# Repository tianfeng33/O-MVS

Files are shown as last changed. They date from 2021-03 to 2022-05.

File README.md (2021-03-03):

# O-MVS
The PCB designs for the Open MVS
These were made and released public in the hopes of promoting the simple, correct and safe consolitation of MVS systems and projects. 
This is V1.3 of the boards designed for the O-MVS project.  

These were designed using EASYEDA and I don't have a schematic specific for this design.
The KiCAD files were generated using https://wokwi.com/easyeda2kicad and have not be checked or tested for accuracy. 
They are meant for people to develop or modify so they can create derivative projects.

If you wish to use the project as is, please have boards made using the Gerbers or the files on OSH PARK. 
These have been tested thoroughly and I hold no responsibility for any damage to your MVS units or your equipment. 

Have fun and make some cool shit for the community.

TF

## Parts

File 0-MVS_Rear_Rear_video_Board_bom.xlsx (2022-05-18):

ID | Name | Designator | Footprint | Quantity
1 | 47uf/10v | C17,C16 | CP_TANTALUM_CASE-B | 2
2 | 100k | R10,R15 | 0603' 1% | 2
3 | 68pF/50V | C11,C14 | 0603' C0G | 2
4 | 1.33k | R8,R7,R9,R6 | 0603' 1% | 4
5 | 0.1uF/50V | C15,C2,C6,C5,C4,C3, | 0603' x7r | 6
6 | 22uF/10V | C1 | 1210 x7r | 1
7 | 330 | R17,R16 | 0603' 1% | 2
8 | 300k | R11,R14 | 0603' 1% | 2
9 | 10.0k | R13,R12 | 0603' 1% | 2
10 | 5.62k | R5,R4,R3,R2 | 0603' 1% | 4
11 | THS7374IPWR | U1 | TSSOP-14 | 1
12 | 10uf/10v | C10,C13 | 0805' x7r | 2
13 | OPA1678IDR | U2 | SOIC-8 | 1
14 | B6B-XH-A(LF)(SN),2.5mm. | j1 | jst-xh-6p | 1
15 | MD-90SM | CON1 | MD-90SM | 1
16 | B2B-XH-A(LF)(SN),2.5mm | Audio | jst xh 2p | 1
17 | 220uf/10v | C18 | Tantlum Case B | 1
18 | 10uf/10v | C12 | Tantalum Case A | 1
19 | 75ohm | r18 | 0603' 1% | 1

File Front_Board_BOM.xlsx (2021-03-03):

ID | Name | Designator | Footprint | Quantity
1 | 0.1uF/50V | c3 | 0603' x7r | 1
2 | 22uF/10V | C1,C2 | 1210 x7r | 2
3 | 1k | r1 | 0603' 1% | 1
4 | STEF04spur | U1 | DFN 3x3 10L | 1
5 | PB400EEQR1BLK | SW1 |  | 1
6 | PB400OAQR1BLK | SW2 |  | 1
7 | A-DS 15 A/KG-T4S | P1,P2 | Dsub 15 2 row | 2
8 | B6B-XH-A(LF)(SN),2.5mm. | AV-Out | B6B-XH-A(LF)(SN),2.5mm. | 1
9 | B2B-XH-A(LF)(SN),2.5mm | LED | B2B-XH-A(LF)(SN),2.5mm | 1
10 | EBM28DRXH | Jamma | 28x2 3.96 card edge female | 1

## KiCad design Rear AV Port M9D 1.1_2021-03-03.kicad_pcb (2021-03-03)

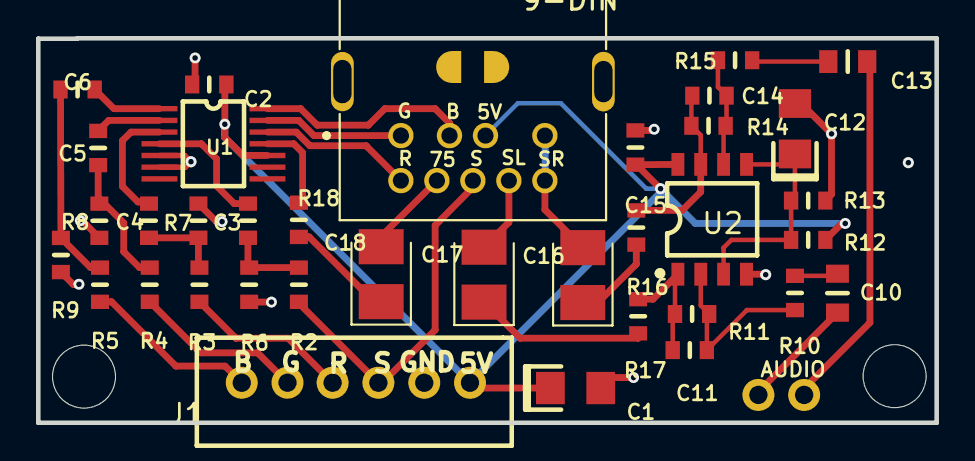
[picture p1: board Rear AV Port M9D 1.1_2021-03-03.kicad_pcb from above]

Board: 2 copper layers, 49.9 x 21.4 mm, 39 parts (0 on the bottom side), 15 nets.

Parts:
9-DIN: MD-90SM; CUI_MD-90SM
AUDIO: JST 2.5
C1, C12: 22uF/10V; 1206_P
C2, C15: 0.1uF/50V; 0603
C3, C4, C5, C6, C11, C14: 270pF/50V; 0603
C10, C13: 0805
C16, C17, C18: CP_TANTALUM_CASE-B_EIA-3528-21_REFLOW
J1: 6PIN_2.54_MM_JST_XHP_JST_CONNECTOR BRO COPY
R2, R3, R4, R5: 5.62k; 0603
R6, R7, R8, R9, R18: 1.00k; 0603
R10, R15: 6.19k; 0603
R11, R14: 162k; 0603
R12, R13: 10.0k; 0603
R16, R17: 332; 0603
U1: THS7374IPWR; TSSOP-14
U2: DMP-8
U5, U6: M3

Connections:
+5V: 9-DIN.2, C1.1, C2.1, C15.1, J1.1, R12.1, U1.10, U2.8
B-OUT: 9-DIN.1, U1.14
BLUE: C6.1, C6.2, J1.6, R5.1, R5.2, R9.2, U1.1
G-OUT: 9-DIN.3, U1.13
GND: 9-DIN.S1, 9-DIN.S2, 9-DIN.S3, C1.2, C2.2, C12.2, C15.2, J1.2, R6.1, R7.1, R8.1, R9.1, R13.1, U1.5, U1.6, U1.9, U2.4
GREEN: C5.1, C5.2, J1.5, R4.1, R4.2, R8.2, U1.2
LEFT: 9-DIN.8, AUDIO.3, C10.1, C10.2, C11.1, C11.2, C17.2, R10.1, R10.2, R11.1, R11.2, R17.2, U2.1, U2.2
R-OUT: 9-DIN.7, U1.12
RED: C4.1, C4.2, J1.4, R3.1, R3.2, R7.2, U1.3
RIGHT: 9-DIN.6, 9-DIN.9, AUDIO.4, C13.1, C13.2, C14.1, C14.2, C16.2, R14.1, R14.2, R15.1, R15.2, R16.1, U2.6, U2.7
SL: C17.1, R17.1
SR: C16.1, R16.2
SYNC: 9-DIN.5, C3.1, C3.2, J1.3, R2.1, R2.2, R6.2, U1.4
SYNC-75: 9-DIN.4, C18.1, C18.2, R18.1, R18.2, U1.11
VREF: C12.1, R12.2, R13.2, U2.3, U2.5

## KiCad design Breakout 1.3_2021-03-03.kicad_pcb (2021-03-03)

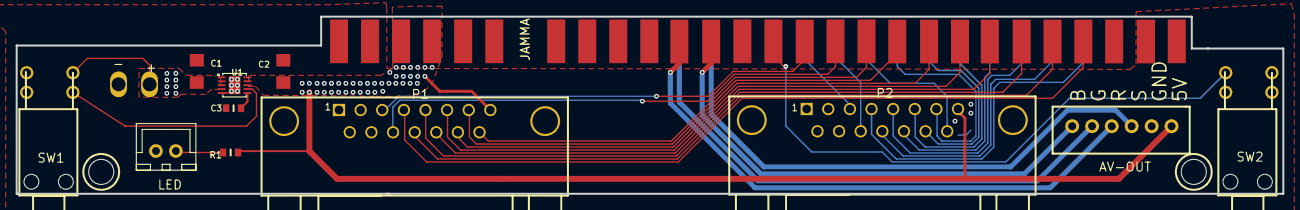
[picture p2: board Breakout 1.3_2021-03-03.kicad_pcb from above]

Board: 2 copper layers, 161.7 x 22.6 mm, 15 parts (0 on the bottom side), 30 nets.

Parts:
+: 3.96MM 2P
C1, C2: R1206
C3: 0.1uF/50V; 0603
J1: 6PIN_2.54_MM_JST_XHP_JST_CONNECTOR BRO COPY
LED: JST_XH_2X2.54
P1, P2: Controller 1; DB15-M-DC
R1: 270pF/50V; 0603
SW1, SW2: PB400EEQR1BLK(CORRECT)
U1: EFUSE
U2, U5: M3 HOLE
U4: JAMMA SOLDER SIDE

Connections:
1PA: P1.13, U4.22
1PB: P1.5, U4.23
1PC: P1.12, U4.24
1PCOIN: P1.3, U4.16
1PD: P1.4, U4.25
1PDN: P1.7, U4.19
1PL: P1.14, U4.20
1PR: P1.6, U4.21
1PST: P1.11, U4.17
1PUP: P1.15, U4.18
2PA: P2.13, U4.Z
2PB: P2.5, U4._A
2PC: P2.12, U4._B
2PCOIN: P2.3, U4.T
2PD: P2.4, U4._C
2PDN: P2.7, U4.W
2PL: P2.14, U4.X
2PR: P2.6, U4.Y
2PST: P2.11, U4.U
2PUP: P2.15, U4.V
+5V: C2.1, J1.1, LED.1, P1.8, P2.8, R1.1, R1.2, U1.8, U1.9, U1.10, U4.3, U4.4, U4.C, U4.D
B: J1.6, U4.13
EN: SW1.4, U1.7
G: J1.5, U4.N
GND: +.1, C1.2, C2.2, C3.2, J1.2, LED.2, P1.0, P1.1, P2.0, P2.1, SW2.2, SW2.4, U1.5, U1.11, U4.1, U4.2, U4.27, U4.28, U4.A, U4.B, U4._E, U4._F
R: J1.4, U4.12
S: J1.3, U4.P
SST: C3.1, U1.6
TEST: SW2.1, U4.15
V-IN: +.2, C1.1, SW1.3, U1.1, U1.2, U1.3, U1.4

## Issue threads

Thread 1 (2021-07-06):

Component BOM unavailable

edacraneo, 2021-07-06:
Hello,
Thanks for your great job, I'm trying to find the material available in the boom file but some products are unavailable. Would it be possible to have up-to-date BOM files? for example, the STEF04spur component cannot be found on the webt, is there an alternative?

Thank you so much

Regards

tianfeng33, 2021-07-07:
Hi,  it might just be the labeling.  https://www.digikey.ca/en/products/detail/stmicroelectronics/STEF4SPUR/4383954?s=N4IgTCBcDaIMoBcCmAzALCAugXyA

It is probably an stef4s now and not 04. That link should work and I will update the bom later today.

edacraneo, 2021-07-07:
Thank you Tianfeng33 for the link but 0 in stock and 28 Weeks for new stock..
Not possible to use another component ? identical please ?

Than you a lot

Regards

tianfeng33, 2021-07-07:
No, just use that since it is not EOL. Arrow has stock.  You just needed to google it. https://www.arrow.com/en/products/stef4spur/stmicroelectronics

edacraneo, 2021-07-07:
yes indeed I was looking for the components especially in France, Thank you again for your help.
Have a nice day

Closed 2021-07-07.

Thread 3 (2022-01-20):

Capacitors

monkzzz, 2022-01-20:
Regarding the tantalum capacitors C12, C16, C17, C18 in the OMVS AV board:
Are they all solid smd or are they polimer?
Is the C12 really a tantalum capacitor? Or a typical MLCC?
Does the C18 really need to be 10v? or can it be a 6,3v?

Glimmerman1984, 2022-03-06:
As above, has the C18 need to be 10V, or can it be 6,3V?
I cant find a Case B 22uF with 10V, only 6,3V or an Case C with 10V.

tianfeng33, 2022-03-07:
C18 should be fine at 6.3v.  C12 needs to be tantalum. The 22uf at c1 can be a ceramic but I would keep it at 10v

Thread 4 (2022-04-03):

Inverted colour?

BulletMag, 2022-04-03:
I have built three av boards now and all appear to have inverted colours resulting in a grey screen with shadowed graphics, audio works fine,
If I take the rgbs feed from the IO board into my GBS-C everything displays as normal.
At first I thought I had just built the unit wrong but after building two more and them also having the same issues I know now that's not the case.
Do you have any suggestions?

tianfeng33, 2022-04-03:
No clue,  it would like something might be connected wrong.  Make sure your sockets are on correctly and the signals are going to the proper places.

BulletMag, 2022-04-03:
I tried this too by individually switching the rgb lines but nothing displays unless sync is connected but again it looks the same...I switched out my scart to a composite lead and got the same result but it was flickering .I am running through a scart to HDMI converter could this cause an issue?On 3 Apr 2022 13:57, TianFeng ***@***.***> wrote:
No clue,  it would like something might be connected wrong.  Make sure your sockets are on correctly and the signals are going to the proper places.

—Reply to this email directly, view it on GitHub, or unsubscribe.You are receiving this because you authored the thread.Message ID: ***@***.***>
On 3 Apr 2022 13:57, TianFeng ***@***.***> wrote:
No clue,  it would like something might be connected wrong.  Make sure your sockets are on correctly and the signals are going to the proper places.

—Reply to this email directly, view it on GitHub, or unsubscribe.You are receiving this because you authored the thread.Message ID: ***@***.***>
On 3 Apr 2022 13:57, TianFeng ***@***.***> wrote:
No clue,  it would like something might be connected wrong.  Make sure your sockets are on correctly and the signals are going to the proper places.

—Reply to this email directly, view it on GitHub, or unsubscribe.You are receiving this because you authored the thread.Message ID: ***@***.***>

tianfeng33, 2022-04-03:
There is no composite from this circut.  It’s just pure rgb.  The composite sync is 75 ohm on pin 4 and ttl on pin 5 following the standard for mini 9 din and hd retrovision cables. Not sure what else it could be.  It’s a pretty simple circuit. The scart to hdmi is likely the issue.  You can msg avram on twitter and see if he has any ideas.

BulletMag, 2022-04-03:
Well I'm happy to confirm the HDMI converter was the issue,After digging around I was able to pull out an only TV with a Scart socket and faster connecting directly to this I was greeted with a perfect picture 😁...This is the same for al three of the boards I have built (I knew I had built them correctly ☺️) I'll just build a lead for my GBS-C now and ditch the HDMI converter.Thanks for your helpOn 3 Apr 2022 15:49, TianFeng ***@***.***> wrote:

There is no composite from this circut.  It’s just pure rgb.  The composite sync is 75 ohm on pin 4 and ttl on pin 5 following the standard for mini 9 din and hd retrovision cables. Not sure what else it could be.  It’s a pretty simple circuit. The scart to hdmi is likely the issue.  You can msg avram on twitter and see if he has any ideas.

—Reply to this email directly, view it on GitHub, or unsubscribe.You are receiving this because you authored the thread.Message ID: ***@***.***>

tianfeng33, 2022-04-03:
Awesome.  That’s good news.  Lots of people have used the gbsc with it so it would be a great combo. Have fun.

hardgb, 2023-11-04:
Is there any way to also obtain the composite signal in this circuit? I would love to get both forms of video signal.

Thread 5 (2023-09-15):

Capacitors Front Board

brendan1495, 2023-09-15:
Hi could you tell me the rating of capacitors C1 & C2 on the front board the bom just says 1210 x7r

tianfeng33, 2023-09-19:
Yeah anything over 5v is fine and with ceramics you are probably getting something way above that likely

brendan1495, 2023-09-20:
Thanks a lot

Vanles, 2024-12-05:
Does the capacitance not matter?

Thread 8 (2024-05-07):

Compatibility

Ign-1, 2024-05-07:
Does Open MVS work with other boards besides the MV1C? (obviously the sound part is different in the others). Thanks!

Sopaco23, 2024-11-29:
I can confirm that the kit is compatible with other models. I have personally installed it in an MV1B and MV1FZ, and can confirm that it requires audio adaptation and a 5V modification.

crabfest, 2025-03-19:
> I can confirm that the kit is compatible with other models. I have personally installed it in an MV1B and MV1FZ, and can confirm that it requires audio adaptation and a 5V modification.

I have a mv1b and I don't know what to do. Have you installed all the audio components in the rear board or did you bypass it all and soldered the L R wires from the stereo mixing board directly into the din pins?

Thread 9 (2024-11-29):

REAR BOARD-MINI DIN 9-(75 POINT)

Sopaco23, 2024-11-29:
On the rear board, there is a point on the mini DIN 9, labelled 75. To connect the device, I only use R, G, B, S, +5 and GND. I am unsure what the function of point 75 is?

Sopaco23, 2024-11-29:
I answer to my self and if it helps anyone.
75=CSYNC 75 ohm attenuated (for comercials CRT)
S= TTL CSYNC

Cyrus331, 2025-01-07:
According to the BOM table, R18 is 75ohm. The table says "BOM_Super gun video_20190909110", but R18 on the engineering PCB is 1K R. There are many places that do not correspond to the BOM table, so I am a bit at a loss.

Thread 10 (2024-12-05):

Front Board - EFUSE

Vanles, 2024-12-05:
What is the exact name of the EFUSE that I need for the front board? I haven't found any further information on this.

Thanks
Marco

anthonydotmoe, 2024-12-31:
I think it is an STEF4S from ST. I found a similar marking on an assembled board and the pins look like they match up to the design.

Sopaco23, 2025-01-16:
The STEF4S is an integrated electronic fuse optimized for monitoring the output current and the input voltage. It can be connected in series to 3.3 V or 5 V rails, protecting the electronic circuitry on its output from overcurrent and overvoltage. The operating mode (5 V or 3.3 V) can be selected by a dedicated pin. The STEF4S has a controlled turn-on time, adjustable by an external capacitor. When an overload condition occurs the device limits the output current to a predefined safe value. If the anomalous overload condition persists it goes into an open state, disconnecting the load from the power supply. If a continuous short-circuit is present on the board, the E-fuse limits the output current to a safe value.
In case of overvoltage on the input, the device clamps the output voltage to a predefined value and protects the load. If the anomalous fault condition persists, the internal thermal protection circuit shuts down the device and then automatically attempts to resupply the load until the fault condition is removed.
Unlike mechanical fuses, which must be physically replaced after a single event, the Efuse does not degrade in its performance after
short-circuit/thermal protection interventions.

[en.DM00095426.pdf](https://github.com/user-attachments/files/18438594/en.DM00095426.pdf)

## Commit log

2021-05-26 Swapped out the op amp
    Decided to swap the audio op amp from the ne5532 to the opa1678.
    [0-MVS_Rear_Rear_video_Board_bom.xlsx]
2022-05-18 Slightly lowered the rgb voltage
    I slightly lowered the RGB voltage to account for different psu voltages with variances on the 5V. 1.4k changed to 1.33k
    [0-MVS_Rear_Rear_video_Board_bom.xlsx]
